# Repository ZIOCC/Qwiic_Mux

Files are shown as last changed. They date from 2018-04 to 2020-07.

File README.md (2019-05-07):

# Zio Qwiic Mux

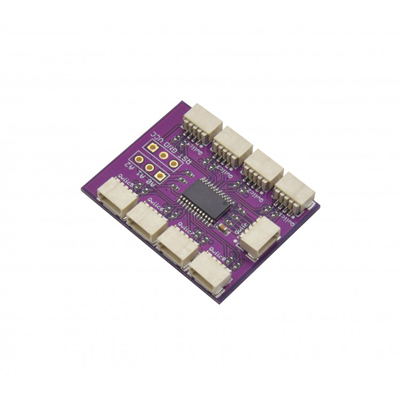
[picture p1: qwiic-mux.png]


> This product can be available for purchase [here](https://www.smart-prototyping.com/Zio-Qwiic-Mux.html).

#### Description

This board is awesome. It lets you switch between sets of Qwiic device chains that are isolated from one another.

That means that you can use up to eight of an I2C device that has a fixed address. And because this board has eight address option itself, you can actually control many more than that.

> The schematic for our Qwiic Mux board is a derivative of the [Adafruit TCA9548A 1-to-8 I2C Multiplexer Breakout](https://learn.adafruit.com/adafruit-tca9548a-1-to-8-i2c-multiplexer-breakout/overview).

One of the limitations of I2C, on which Qwiic is based, is that some sensors only have one or two changeable bits in their address. Some even have a single fixed address. That means that you can’t use more than one of them connected to the same I2C bus on your microcontroller. What if you want to use more than one? Thanks to the handy-dandy Zio Qwiic MUX, you can use up to EIGHT of that fixed-address TOF range-finder module that you want to stick on every side of your drone for automatic collision avoidance. Your shattered dreams of building an I2C-based motion capture suit using BNO080 breakouts? Shattered no more, my friend. We’ve got your sixteen sensors right here.

What’s the trick? The TCA9548APWR is an eight-channel two-wire bus multiplexer. It is, in fact, an I2C device itself. By changing the value of one of the TCA9548APWR’s registers, you can route the connection from your MCU to any of eight pairs of pins, each with their own set of pullup resistors (optional, via solder jumpers), on the other side of this IC. It’s a lot like a railroad track switch. Want to know what else is cool about that? It overcomes the 4-foot wire-length limitation of Qwiic. Each one of those ports counts as a different bus.

We don’t do any voltage level shifting on these ports. Each and every one is an unadulterated 3.3v Qwiic port. The TCA9548APWR also has three configurable address bits, so you can use up to eight of them on the same bus. Or you can get really crazy and connect eight other Zio Qwiic MUX boards, all with the same address, to each of the eight ports on your first Zio Qwiic MUX. And then… well, exponents being what they are, you could split your one I2C bus into over sixteen million of them using only these boards. That is, if you had the money and space and inclination. Frankly speaking, we don’t recommend it. But if you want to place an order for the two million or so boards necessary to do it, we could probably work out some kind of volume discount for you. Just don’t ask us to offer a power supply solution for that.

#### Specification

* Weight: 2.6g (0.09oz)
* IC: TCA9548A
* I2C address: 0x70- 0x77
* Default:0x70

#### Links

* [TCA9548A datasheet](https://www.smart-prototyping.com/image/data/NOA-RnD/101900%20Mux/tca9548a.pdf)
* [Example Code- Connect two TOF sensor with Mux](https://www.smart-prototyping.com/image/data/NOA-RnD/101900%20Mux/Zio_Qwiic_Mux_TOF_Example_Code.zip)
* [Eagle files](https://github.com/ZIOCC/Qwiic_Mux)

##### Connections for example code



Adafruit also has a [great little tutorial](https://learn.adafruit.com/adafruit-tca9548a-1-to-8-i2c-multiplexer-breakout/wiring-and-test) with some very simple Arduino functions for using it, the most important being:
<pre>
<code>
#define TCAADDR 0x70
void tcaselect(uint8_t i) {
  if (i > 7) return;
  Wire.beginTransmission(TCAADDR);
  Wire.write(1 << i);
  Wire.endTransmission();
}
</code>
</pre>

Just drop that into your sketch and then call <code>tcaselect(x);</code> where x is the port, from 0 to 7, that you want to activate.

And to disable all of the ports (in the case that you're using more than one of these board, and need to prevent an address collision between identical devices connected to each) just call this function with that Qwiic Mux's address (set by soldering closed a combination of the A0, A1, and A2 jumpers on the bottom of the PCB) as the only argument:

<pre><code>
void tcadisable(uint8_t tcaaddress){<br>
  Wire.beginTransmission(tcaaddress);<br>
  Wire.write(0);  // no channel selected<br>
  Wire.endTransmission();<br>
}<br>
</code></pre>

> All Zio products are released under the [Creative Commons Attribution, Share-Alike License](https://creativecommons.org/licenses/by-sa/4.0/), and in accordance with the principles of the [Open Source Hardware Association's OSHW Statement of Principles 1.0 and OSHW Definition 1.0](https://www.oshwa.org/definition/).

> ###### About Zio
> Zio is a new line of open sourced, compact, and grid layout boards, fully integrated for Arduino and Qwiic ecosystem. Designed ideally for wearables, robotics, small-space limitations or other on the go projects. Check out other awesome Zio products [here](https://www.smart-prototyping.com/Zio).

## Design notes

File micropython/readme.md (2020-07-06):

#### Usage
When you need to put more than 1 same I2C address device, usually you will need to use two different I2C port from MCU, or you can choose this Multipluxer to solve this I2C address conflict issue.

#### Demo code:
In this demo code, I used two ToF sensors, you can change to other I2C devices for the ToF part. 

```  
from machine import Pin,I2C
import mux
import rfd77402

i2c = I2C(sda=Pin("Y10"), scl=Pin("Y9"), freq =50000)

print(i2c.scan())
mux = mux.MUX(i2c,0x70)
tof = rfd77402.RFD77402(i2c,0x4C)

#ToF initiation
mux.enable_mux_port(0)
tof.begin()
pyb.delay(100)
mux.disable_mux_port(0)
mux.enable_mux_port(1)
tof.begin()
pyb.delay(100)
mux.disable_mux_port(1)

while True:
    mux.enable_mux_port(0)
    tof.takeMeasurement()
    t = tof.getDistance()
    print("tof 0: " + str(t))
    mux.disable_mux_port(0)
    # pyb.delay(50)
    mux.enable_mux_port(1)
    tof.takeMeasurement()
    t = tof.getDistance()
    print("tof 1: " + str(t))
    mux.disable_mux_port(1)
    # pyb.delay(50)

```  

#### Product link:
[Zio Qwiic Mux (8 multiplexed Qwiic I2C Busses)](https://www.smart-prototyping.com/Zio-Qwiic-Mux.html)
[Zio TOF Distance Sensor RFD77402 (Qwiic, 10 to 200cm)](https://www.smart-prototyping.com/Zio-TOF-Distance-Sensor-RFD77402.html)

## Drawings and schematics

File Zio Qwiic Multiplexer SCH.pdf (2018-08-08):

1 | 2 | 3 | 4 | 5 | 6

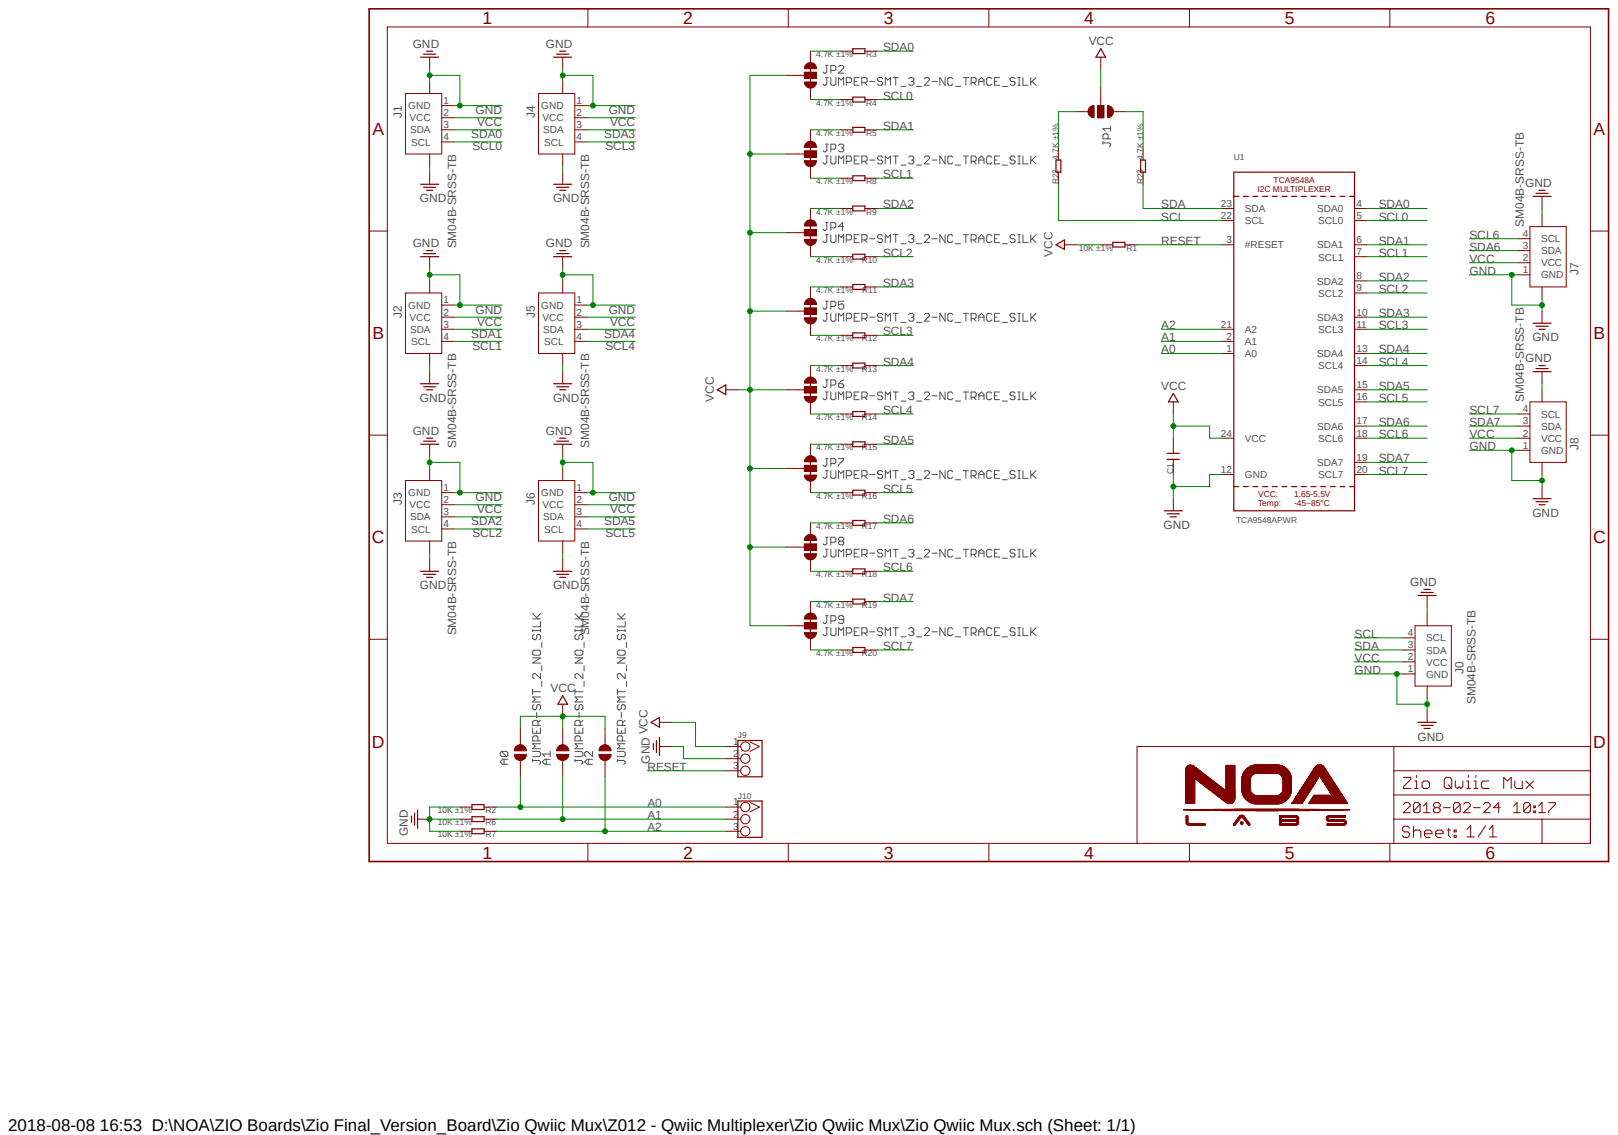
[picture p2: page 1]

2018-08-08 16:53 D:\NOA\ZIO Boards\Zio Final_Version_Board\Zio Qwiic Mux\Z012 - Qwiic Multiplexer\Zio Qwiic Mux\Zio Qwiic Mux.sch (Sheet: 1/1)

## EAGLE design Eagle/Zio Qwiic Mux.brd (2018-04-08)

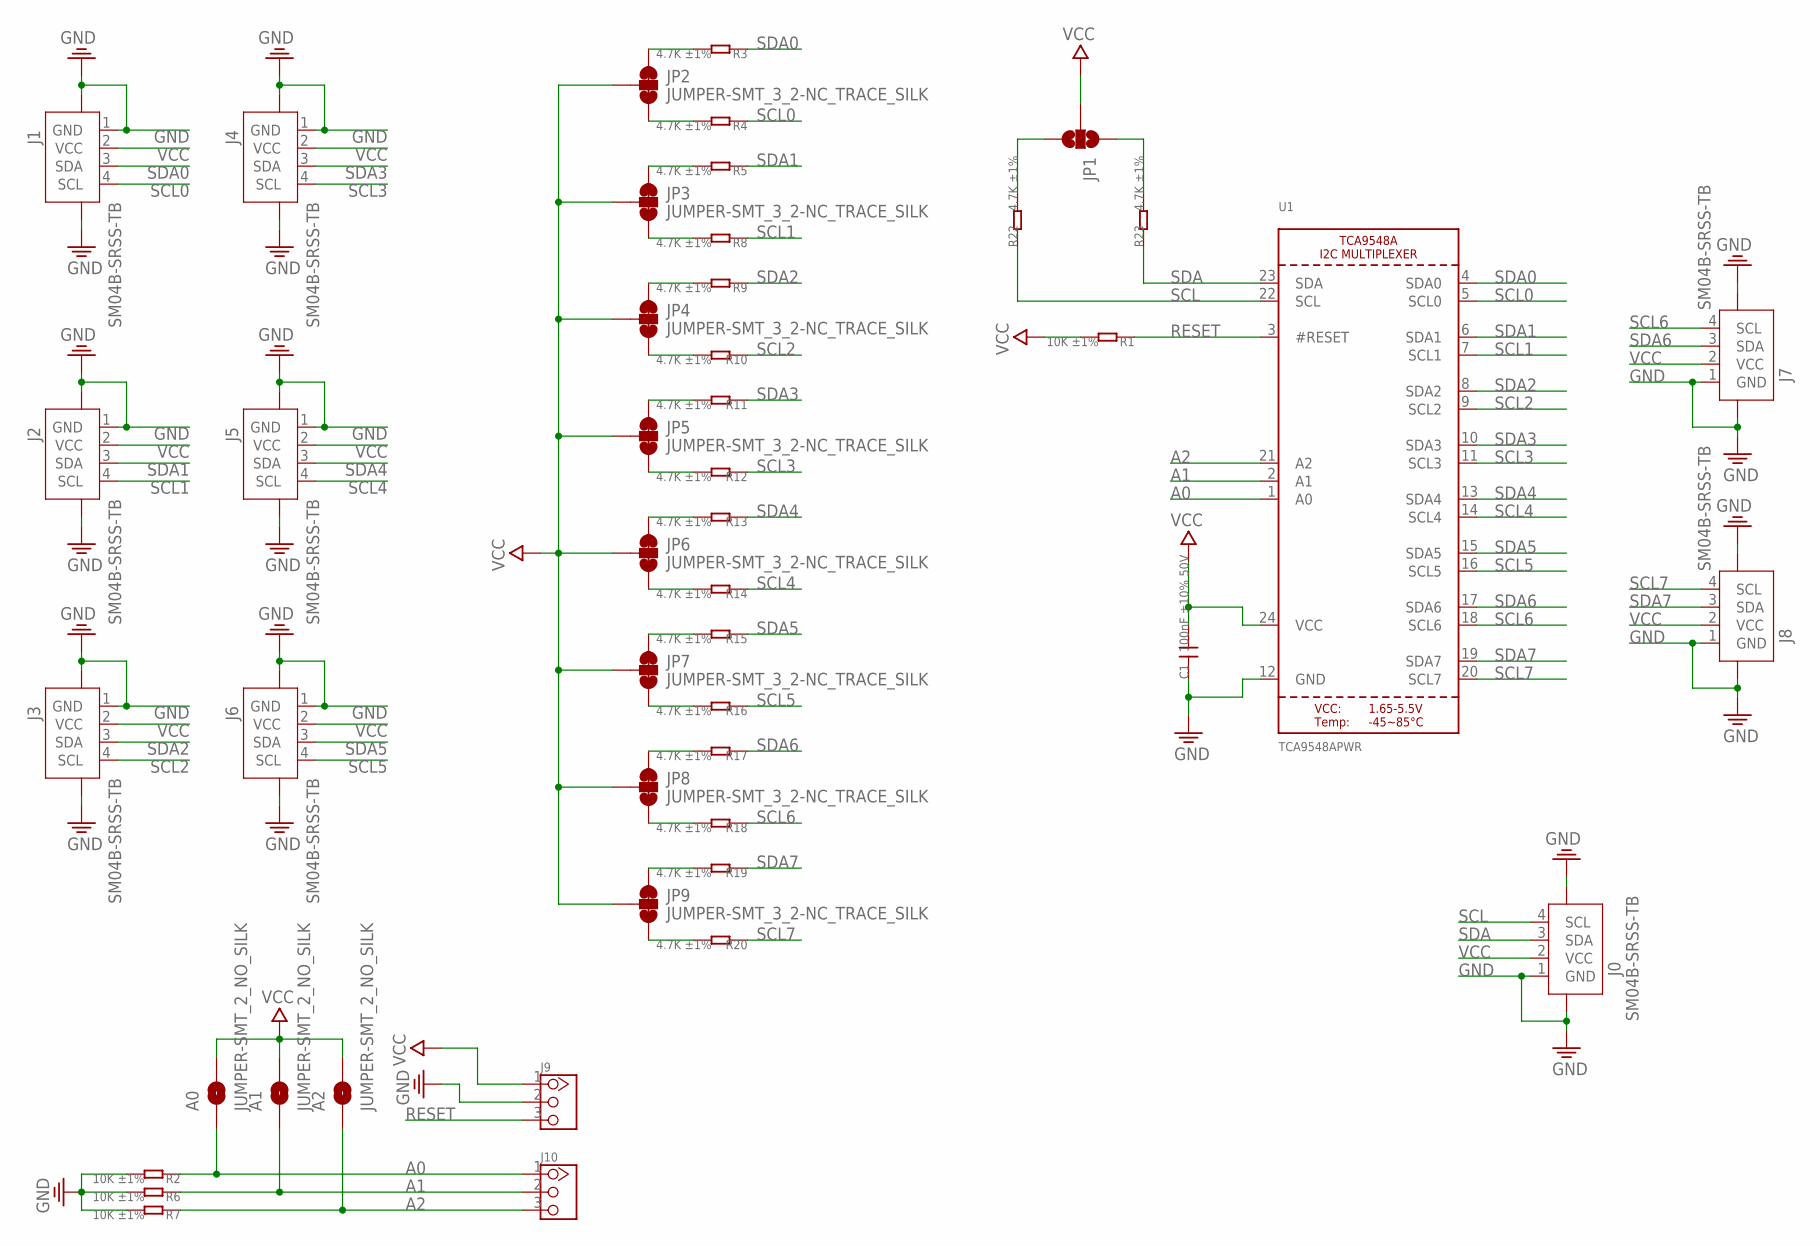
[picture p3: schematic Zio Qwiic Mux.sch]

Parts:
A0, A1, A2: JUMPER-SMT_2_NO_SILK; SMT-JUMPER_2_NO_SILK
C1: 100nF ±10% 50V; 0603
J0, J1, J2, J3, J4, J5, J6, J7, J8: SM04B-SRSS-TB; JST-SH-4P
J9, J10: HEADER-3P-2.54; 3P-2.54
JP1: JUMPER-SMT_3_2-NC_PASTE_NOCREM; SMT-JUMPER_3_2-NC_PASTE_SILK_NOCREM
JP2, JP3, JP4, JP5, JP6, JP7, JP8, JP9: JUMPER-SMT_3_2-NC_TRACE_SILK; SMT-JUMPER_3_2-NC_TRACE_SILK
R1, R2, R6, R7: 10K ±1%; 0402
R3, R4, R5, R8, R9, R10, R11, R12, R13, R14, R15, R16, R17, R18, R19, R20, R22, R23: 4.7K ±1%; 0402
U1: TCA9548APWR; TSSOP24

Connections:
A0: A0.1, J10.1, R2.1, U1.1 (A0)
A1: A1.1, J10.2, R6.1, U1.2 (A1)
A2: A2.1, J10.3, R7.1, U1.21 (A2)
GND: C1.1, J0.1 (GND), J0.NC1 (5), J0.NC2 (6), J1.1 (GND), J1.NC1 (5), J1.NC2 (6), J2.1 (GND), J2.NC1 (5), J2.NC2 (6), J3.1 (GND), J3.NC1 (5), J3.NC2 (6), J4.1 (GND), J4.NC1 (5), J4.NC2 (6), J5.1 (GND), J5.NC1 (5), J5.NC2 (6), J6.1 (GND), J6.NC1 (5), J6.NC2 (6), J7.1 (GND), J7.NC1 (5), J7.NC2 (6), J8.1 (GND), J8.NC1 (5), J8.NC2 (6), J9.2, R2.2, R6.2, R7.2, U1.12 (GND)
unnamed: JP2.1, R3.2
unnamed: JP2.3, R4.2
unnamed: JP3.1, R5.2
unnamed: JP3.3, R8.2
unnamed: JP4.1, R9.2
unnamed: JP4.3, R10.2
unnamed: JP5.1, R11.2
unnamed: JP5.3, R12.2
unnamed: JP1.3, R22.2
unnamed: JP1.1, R23.2
unnamed: JP6.1, R13.2
unnamed: JP6.3, R14.2
unnamed: JP7.1, R15.2
unnamed: JP7.3, R16.2
unnamed: JP8.1, R17.2
unnamed: JP8.3, R18.2
unnamed: JP9.1, R19.2
unnamed: JP9.3, R20.2
RESET: J9.3, R1.1, U1.3 (#RESET)
SCL: J0.4 (SCL), R22.1, U1.22 (SCL)
SCL0: J1.4 (SCL), R4.1, U1.5 (SCL0)
SCL1: J2.4 (SCL), R8.1, U1.7 (SCL1)
SCL2: J3.4 (SCL), R10.1, U1.9 (SCL2)
SCL3: J4.4 (SCL), R12.1, U1.11 (SCL3)
SCL4: J5.4 (SCL), R14.1, U1.14 (SCL4)
SCL5: J6.4 (SCL), R16.1, U1.16 (SCL5)
SCL6: J7.4 (SCL), R18.1, U1.18 (SCL6)
SCL7: J8.4 (SCL), R20.1, U1.20 (SCL7)
SDA: J0.3 (SDA), R23.1, U1.23 (SDA)
SDA0: J1.3 (SDA), R3.1, U1.4 (SDA0)
SDA1: J2.3 (SDA), R5.1, U1.6 (SDA1)
SDA2: J3.3 (SDA), R9.1, U1.8 (SDA2)
SDA3: J4.3 (SDA), R11.1, U1.10 (SDA3)
SDA4: J5.3 (SDA), R13.1, U1.13 (SDA4)
SDA5: J6.3 (SDA), R15.1, U1.15 (SDA5)
SDA6: J7.3 (SDA), R17.1, U1.17 (SDA6)
SDA7: J8.3 (SDA), R19.1, U1.19 (SDA7)
VCC: A0.2, A1.2, A2.2, C1.2, J0.2 (VCC), J1.2 (VCC), J2.2 (VCC), J3.2 (VCC), J4.2 (VCC), J5.2 (VCC), J6.2 (VCC), J7.2 (VCC), J8.2 (VCC), J9.1, JP1.2, JP2.2, JP3.2, JP4.2, JP5.2, JP6.2, JP7.2, JP8.2, JP9.2, R1.2, U1.24 (VCC)

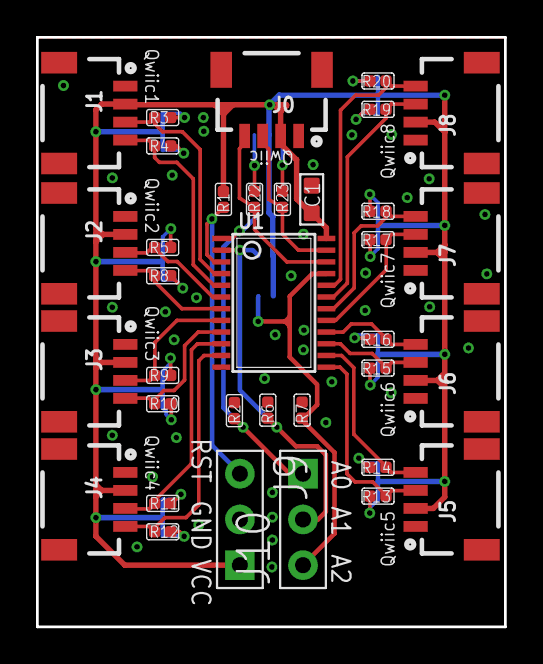
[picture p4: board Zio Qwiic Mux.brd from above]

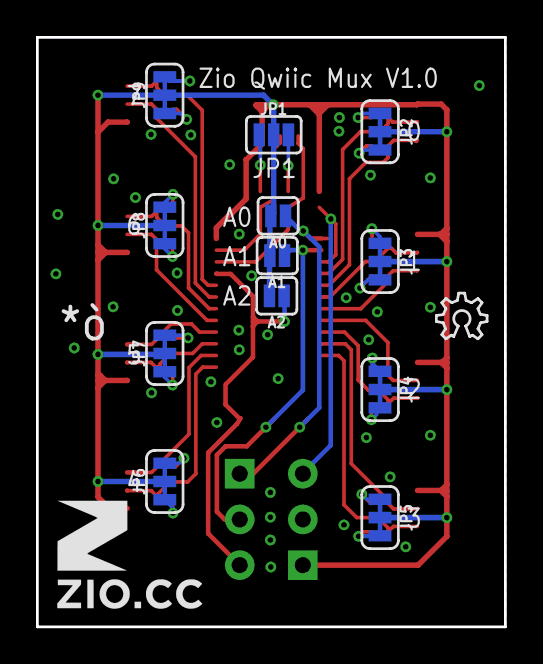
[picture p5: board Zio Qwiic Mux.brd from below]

Board: 2 copper layers, 26.0 x 32.8 mm, 49 parts (14 on the bottom side), 42 nets.

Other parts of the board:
U$7: 6MM
U$8: OSHW_6X100_NOTEXT

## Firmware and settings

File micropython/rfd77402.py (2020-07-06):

'''
Auther: Alex Chu
Website: www.smart-prototyping.com
Email: shop@smart-prototyping.com
product link: https://www.smart-prototyping.com/Zio-TOF-Distance-Sensor-RFD77402.html
RFD77402 datasheet: https://www.smart-prototyping.com/image/data/NOA-RnD/101891%20TOF/RFD77402DatasheetRev1-8.pdf
#reference: https://github.com/sparkfun/SparkFun_RFD77402_Arduino_Library/tree/master/src
'''

from machine import Pin,I2C
import pyb

RFD77402_ICSR = 0x00
RFD77402_INTERRUPTS = 0x02
RFD77402_COMMAND = 0x04
RFD77402_DEVICE_STATUS = 0x06
RFD77402_RESULT = 0x08
RFD77402_RESULT_CONFIDENCE= 0x0A
RFD77402_CONFIGURE_A = 0x0C
RFD77402_CONFIGURE_B = 0x0E
RFD77402_HOST_TO_MCPU_MAILBOX = 0x10
RFD77402_MCPU_TO_HOST_MAILBOX = 0x12
RFD77402_CONFIGURE_PMU = 0x14
RFD77402_CONFIGURE_I2C = 0x1C
RFD77402_CONFIGURE_HW_0 = 0x20
RFD77402_CONFIGURE_HW_1 = 0x22
RFD77402_CONFIGURE_HW_2 = 0x24
RFD77402_CONFIGURE_HW_3 = 0x26
RFD77402_MOD_CHIP_ID = 0x28

RFD77402_MODE_MEASUREMENT = 0x01
RFD77402_MODE_STANDBY = 0x10
RFD77402_MODE_OFF = 0x11
RFD77402_MODE_ON = 0x12

CODE_VALID_DATA = 0x00
CODE_FAILED_PIXELS = 0x01
CODE_FAILED_SIGNAL = 0x02
CODE_FAILED_SATURATED = 0x03
CODE_FAILED_NOT_NEW = 0x04
CODE_FAILED_TIMEOUT = 0x05

I2C_SPEED_STANDARD = 100000
I2C_SPEED_FAST = 400000

INT_CLR_REG = 1 # tells which register read clears the interrupt (Default: 1, Result Register)
INT_CLR = 0 << 1 # tells whether or not to clear when register is read (Default: 0, cleared upon register read)
INT_PIN_TYPE = 1 << 2 # tells whether int is push-pull or open drain (Default: 1, push-pull)
INT_LOHI = 0 << 3 # tells whether the interrupt is active low or high (Default: 0, active low)

# Setting any of the following bits to 1 enables an interrupt when that event occurs
INTSRC_DATA = 1      # Interrupt fires with newly available data
INTSRC_M2H = 0 << 1  # Interrupt fires with newly available data in M2H mailbox register
INTSRC_H2M = 0 << 2  # Interrupt fires when H2M register is read
INTSRC_RST = 0 << 3  # Interrupt fires when HW reset occurs


class RFD77402:

    def __init__(self,i2c,addr):
        self.addr = addr
        self.i2c = i2c
        self.distance = 0
        self.validPixels = 0
        self.confidenceValue = 0
        self.calibrationData =[]
        self.cmd_1_byte =bytearray(1)
        self.cmd_2_byte = bytearray(2)

    def begin(self):
        if self.getChipID() < 0xAD00:
            return False
        # Deivce power on flow, from datasheet page 29
        if self.goToStandbyMode() == False:
            return False
        # Drive INT_PAD high
        setting = self.i2c.readfrom_mem(self.addr, RFD77402_ICSR, 1)
        # clears writable bits
        setting_int = setting[0] & 0b11110000
        # change bits to enable interrupt
        setting_int |= INT_CLR_REG | INT_CLR | INT_PIN_TYPE | INT_LOHI
        self.cmd_1_byte[0] = setting_int
        self.i2c.writeto_mem(self.addr, RFD77402_ICSR, self.cmd_1_byte)
        setting = self.i2c.readfrom_mem(self.addr, RFD77402_INTERRUPTS, 1)
        # Clears bits
        setting_int = setting[0] & 0b00000000
        # setting = 0b00000000
        setting_int |= INTSRC_DATA | INTSRC_M2H | INTSRC_H2M | INTSRC_RST
        self.cmd_1_byte[0] = setting_int
        # setting |= INTSRC_DATA | INTSRC_M2H | INTSRC_H2M | INTSRC_RST  # Enables interrupt when data is ready
        self.i2c.writeto_mem(self.addr, RFD77402_INTERRUPTS, self.cmd_1_byte) # 1 byte
        # Configure I2C Interface,
        # //0b.0110.0101 = 0x65 Address increment, auto increment, host debug, MCPU debug, 2.1.3 setting
        self.i2c.writeto_mem(self.addr, RFD77402_CONFIGURE_I2C, b'\x65')
        # //0b.0000.0101.0000.0000 //Patch_code_id_en, Patch_mem_en
        self.i2c.writeto_mem(self.addr, RFD77402_CONFIGURE_PMU, b'\x00\x05')  # 0x0500
        if self.goToOffMode() == False:
            return False
        # set initialization - Magic from datasheet. Write 0x0600 to 0x14 location
        self.i2c.writeto_mem(self.addr, RFD77402_CONFIGURE_PMU, b'\x00\x06') # 0x0600
        if self.goToOnMode() == False:
            return False
        # set peak and threshold 0xe100
        self.i2c.writeto_mem(self.addr, RFD77402_CONFIGURE_A, b'\x00\xe1')
        self.i2c.writeto_mem(self.addr, RFD77402_CONFIGURE_B, b'\xff\x10') # Set valid pixel. Set MSP430 default config. cmd: 0x10FF
        self.i2c.writeto_mem(self.addr, RFD77402_CONFIGURE_HW_0, b'\xd0\x07') # Set saturation threshold = 2,000.   cmd:0x07D0
        self.i2c.writeto_mem(self.addr, RFD77402_CONFIGURE_HW_1, b'\x08\x50') # Frequecy = 5. Low level threshold = 8, cmd: 0x5008
        self.i2c.writeto_mem(self.addr, RFD77402_CONFIGURE_HW_2, b'\x41\xa0') # cmd: 0xA041. Integration time = 10 * (6500-20)/15)+20 = 4.340ms. Plus reserved magic.
        self.i2c.writeto_mem(self.addr, RFD77402_CONFIGURE_HW_3, b'\xd4\x45') # cmd: 0x45D4. Enable harmonic cancellation. Enable auto adjust of integration time. Plus reserved magic.
        # Error - MCPU never went to standby
        if self.goToStandbyMode() == False:
            return False
        # Set initialization - Magic from datasheet. Write 0x05 to 0x15 location.
        self.i2c.writeto_mem(self.addr, RFD77402_CONFIGURE_PMU, b'\x00\x05')
        if self.goToOffMode() == False:
            return False
        # Set initialization - Magic from datasheet. Write 0x06 to 0x15 location.
        self.i2c.writeto_mem(self.addr, RFD77402_CONFIGURE_PMU, b'\x00\x06')
        if self.goToOnMode() == False:
            return False
        return True

    # Single Measure Flow, from datasheet page 30
    def takeMeasurement(self):
        if self.goToMeasurementMode() == False:
            return CODE_FAILED_TIMEOUT
        resultRegister = self.i2c.readfrom_mem(self.addr, RFD77402_RESULT,2)
        resultRegister_int = (resultRegister[1]<<8) | resultRegister[0]
        if resultRegister_int & 0x7FFF:
            errorCode = (resultRegister[1] >> 5) & 0x03
            if errorCode == 0:
                self.distance = ((resultRegister[1] & 0x1F) << 8) | resultRegister[0] # Distance is good. Read it.
                self.distance = self.distance >> 2
                confidenceRegister = self.i2c.readfrom_mem(self.addr, RFD77402_RESULT_CONFIDENCE, 2)
                confidenceRegister_int = (confidenceRegister[1] << 8) | confidenceRegister[0]
                self.validPixels = confidenceRegister_int & 0x0F
                self.confidenceValue = (confidenceRegister_int >> 4) & 0x07FF
            else:
                return errorCode
        else:
            return CODE_FAILED_NOT_NEW

    def getDistance(self):
        return self.distance

    def getValidPixels(self):
        return self.validPixels

    def getConfidenceValue(self):
        return self.confidenceValue

    def getMode(self):
        return (self.i2c.readfrom_mem(self.addr, RFD77402_COMMAND,1)[0] & 0x3F)
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

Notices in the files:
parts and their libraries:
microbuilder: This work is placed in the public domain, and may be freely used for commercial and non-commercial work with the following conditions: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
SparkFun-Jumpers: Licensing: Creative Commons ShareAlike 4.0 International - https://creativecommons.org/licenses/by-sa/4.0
